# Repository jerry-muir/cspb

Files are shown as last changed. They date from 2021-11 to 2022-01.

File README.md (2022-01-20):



# Cluster System Power Board

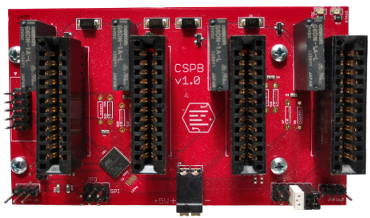
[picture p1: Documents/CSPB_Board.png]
CSPB


## About

The Cluster System Power Board (CSPB) is a power distribution and control platform to simplify the construction of Single Board Computer Clusters. The power board is designed to allow for simple single cluster systems or complex multi board systems to be powered through one power supply and controlled from a single control module. Control of the power board is achieved via an i2c serial bus interface which can be chained across multiple power boards.
<br />

## The project
The project has three main components. The hardware design which can be found in the [Hardware](/Hardware) directory, the firmware code which can be found in the [Firmware](/Firmware) directory and some user interface software which can be found in the [Software](/Software) directory.

A detailed users manual can be found in the [Documents](\Documents)
 directory.
## Python package links:

[PIP cspb Package](https://pypi.org/project/cspb/)
<br />
[PIP cspb-tools Package](https://pypi.org/project/cspb-tools/)

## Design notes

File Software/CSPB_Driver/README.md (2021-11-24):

# cspb

The cspb package contains a python driver class for communications with the Cluster System Power Board (cspb) hardware.

## Introduction

The cspb package contains a wrapper driver around the smbus package. It enables easy communication with the cluster system power board hardware via an i2c bus.

Currently supported methods are:

- set_power

- shutdown

- signal_shutdown

- read_register

- write_register

- set_register_number

- send_command

## Dependencies

This driver depends on the [smbus](https://pypi.org/project/smbus/) package.

## CSPB code examples

### Example 1: Display the current power state

```
from cspb.CSPB import CSPB

i2c_bus_number = 1
i2c_address = 21
cspb = CSPB(i2c_bus_number, i2c_address)
power_state = cspb.read_register(cspb.PWR_STTS_REGSTR_ADDR)
print(power_state)
```

### Example 2: Request shutdown of all power slots

```
from cspb.CSPB import CSPB

i2c_bus_number = 1
i2c_address = 21
cspb = CSPB(i2c_bus_number, i2c_address)
cspb.shutdown(0xff)
```

## Installation Instructions

cspb is a pure Python and requires no compilation. Install as follows:

```
pip install cspb
```

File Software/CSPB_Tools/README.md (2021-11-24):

# cspb-tools

The Cluster System Power Board (cspb) tools package contains example python software for communicating with the cluster system power board hardware.

## Introduction

The cspb-tools package contains python code examples that make use of the cspb driver package to provide communications to the cluster system power board hardware via an i2c serial bus. The software was developed with a focus on the Raspberry Pi single board computer.

This package contains the following programs:

- cspb_gui:

     A basic graphical user interface for communicating with and programming 
the cspb hardware.

## Dependencies

This package depends on the [cspb](https://pypi.org/project/cspb/) package.

## Code Examples

Running the GUI application:

```
run_cspb_gui
```

## Installation Instructions

The cspb_tools package is pure Python and requires no compilation. Install as follows:

```
pip install cspb_tools
```

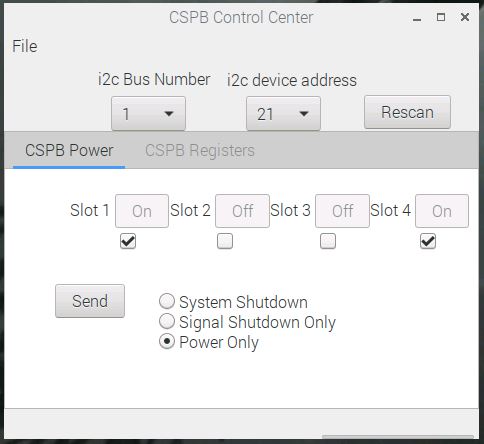
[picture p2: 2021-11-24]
Software/CSPB_Tools/app_pic.JPG

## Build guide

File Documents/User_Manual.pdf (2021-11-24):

# User Manual

## Cluster System Power Board

Version 1.1

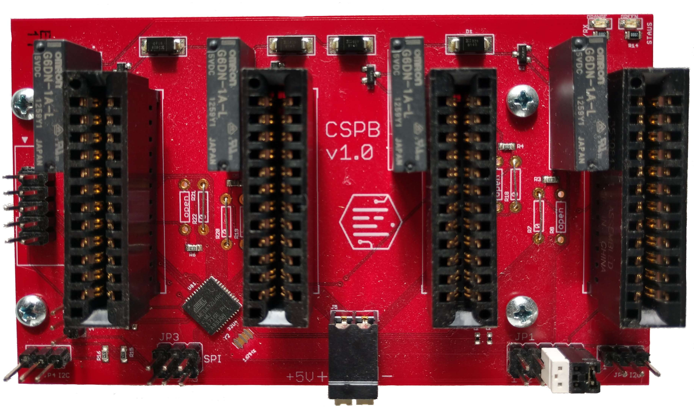
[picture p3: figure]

Version 1.1 | Page 1

Version 1.1 | Page 2

## Table of Contents

Version 1.1 | Page 3

Version 1.1 | Page 4

## Introduction

The Cluster System Power Board (CSPB) is a power distribution and control platform to simplify the construction of Single Board Computer Clusters. The power board is designed to allow for simple single cluster systems or complex multi board systems to be powered through one power supply and controlled from a single control module. Control of the power board is achieved via an i2c serial bus interface which can be chained across multiple power boards.

## Functional Description

The CSPB is a micro-controller based power board that allows easy control of power to individual single board computers. Each power board can hold up to four single board computers that conform to the Raspberry Pi 40 pin IO connector standard.
The CSPB is controlled via an i2c serial interface which can be connected to any i2c capable module via the i2c bus connector. Slot 1 of the CSPB is also available as an i2c bus connection via jumper terminals. This allows slot 1 to be the i2c control module for the CSPB.
Because the CSPB is controlled via an i2c interface, power boards can be chained together to form larger cluster systems that can be powered from one power supply and managed from one controller module. Each CSPB can be configured with a unique i2c address.
The CSPB can power on or off each slot individually, allowing single board computers to be added or removed with out impacting the cluster. The CSPB can also be configured to power up individual slots during it’s initial power up sequence. During the initial power up sequence a slot power up delay can be programmed to help manage current draw on the power supply.
The CSPB supports software shutdown of individual slots. The CSPB will signal the single board computer to perform a shutdown and wait for a control line to change state before removing power to the slot. This function has a programmable time out to ensure power down is completed.
The CSPB supports querying of the slot power states and shutdown states through register reads. Both programmable register functions and readable register functions are describe in more detail in the Registers section on page 17.
Jumper settings can be used to program default i2c addresses and i2c bus connections. Jumper settings are detailed in the Jumper Settings section on page 20.
The CSPB is power with 5.1V through a screwless spring loaded terminal block. The power circuit provides revers polarity protection.
The CSPB has two LED indicators, one for active power to the board and a second to indicate micro-controller activity during command processing.
Version 1.1 | Page 5

The CSPB can be mounted to a chassis or other mounting surface via the four 2.75mm mounting holes.

## Typical Configurations:

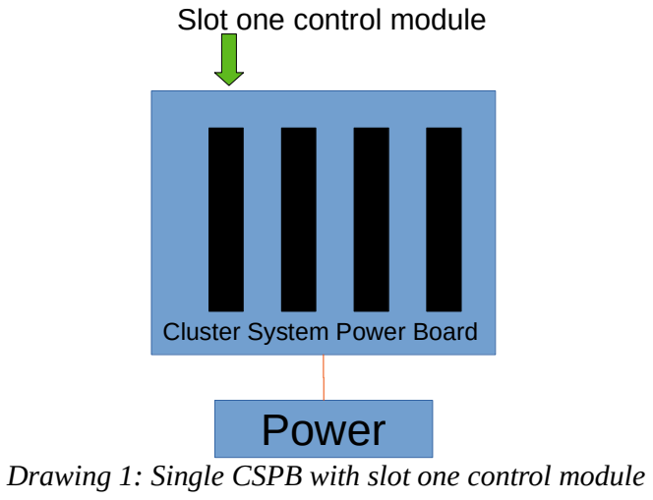
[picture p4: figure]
Power; Slot one control module; Cluster System Power Board
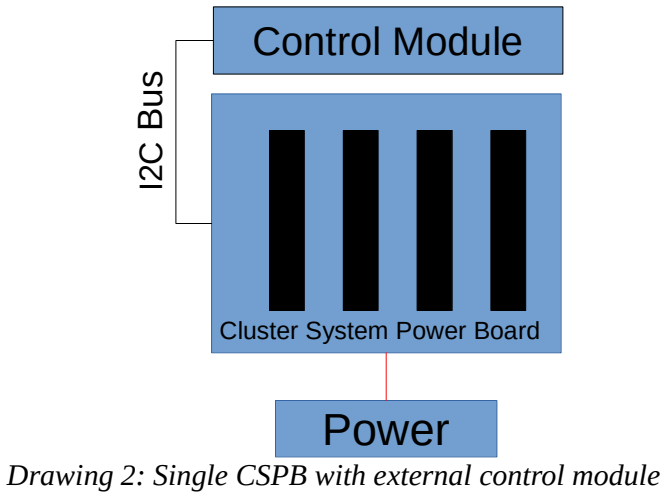
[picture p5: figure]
Power; Control Module; Cluster System Power Board

Version 1.1 | Page 6

Drawing 2: Single CSPB with external control module I2C Bus

Drawing 1: Single CSPB with slot one control module

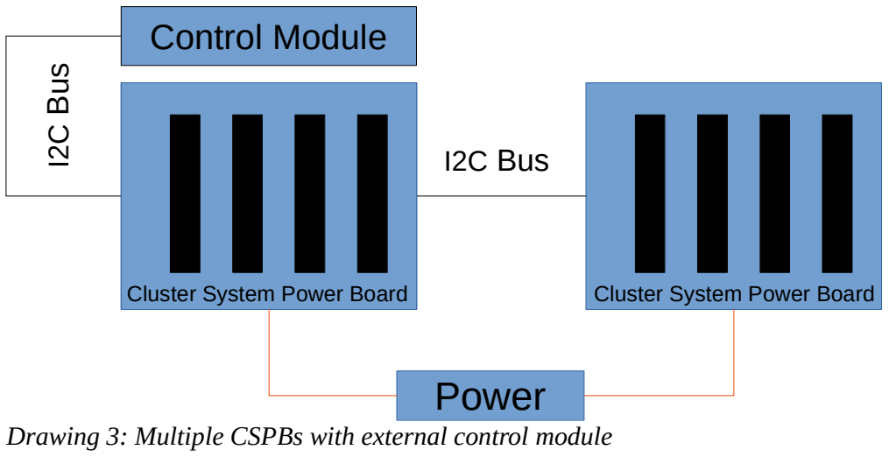
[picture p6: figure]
Control Module; Power; I2C Bus
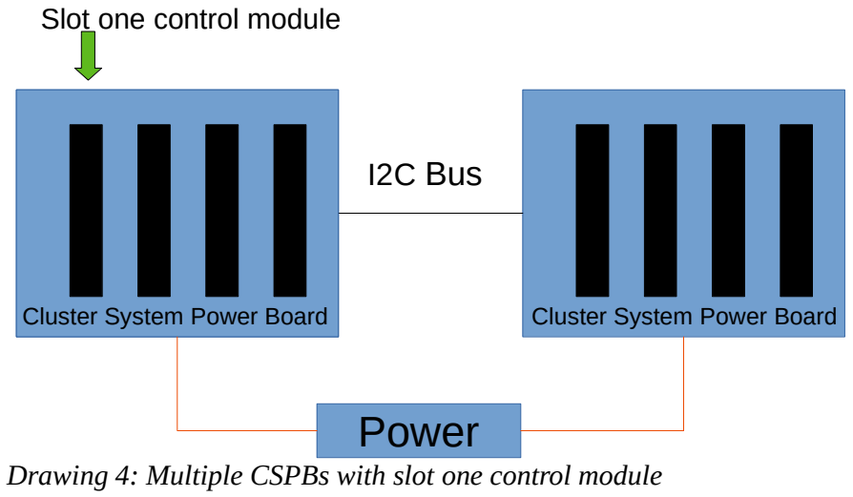
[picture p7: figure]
Cluster System Power Board; Power; I2C Bus; Slot one control module

Version 1.1 | Page 7

Drawing 3: Multiple CSPBs with external control module

Cluster System Power Board | Cluster System Power Board I2C Bus

Drawing 4: Multiple CSPBs with slot one control module

Cluster System Power Board | Cluster System Power Board

## Hardware Description

## Board Layout

The CSPB provides software controlled power distribution to the connected single board computers. There is a push terminal power connector for easy connection to a central power supply. LED indicators are provided for ‘power on’ and ‘board status’. Two i2c connectors are located at either end of the board and can be used to connect to a controller module and or to chain CSPB together is so desired. A jumper block is provided for configuring i2c bus connections and default address settings.

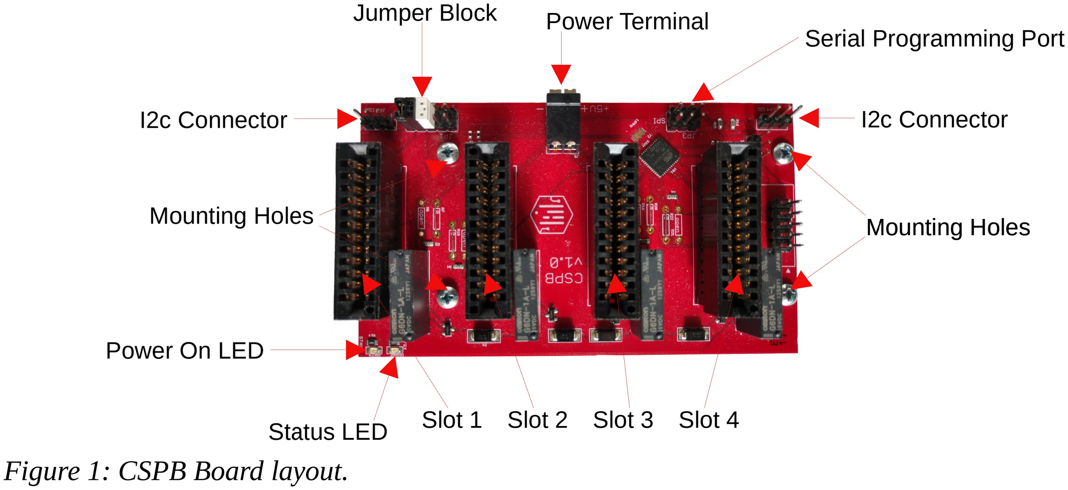
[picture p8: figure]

## Power Specification

The power specification below were developed with the Raspberry Pi single board computer in mind, however other single board computers using the Raspberry Pi 40 pin header specification should also work.

Parameter | Value | Min | Max
Input Voltage¹ | 5.1 V | 4.75 V | 5.25 V
Nominal Current | 218 mA²

1 The input voltage can vary according to the single board computer requirements. 2 This value does not include the current draw of the single board computers.

Version 1.1 | Page 8

## Dimensions

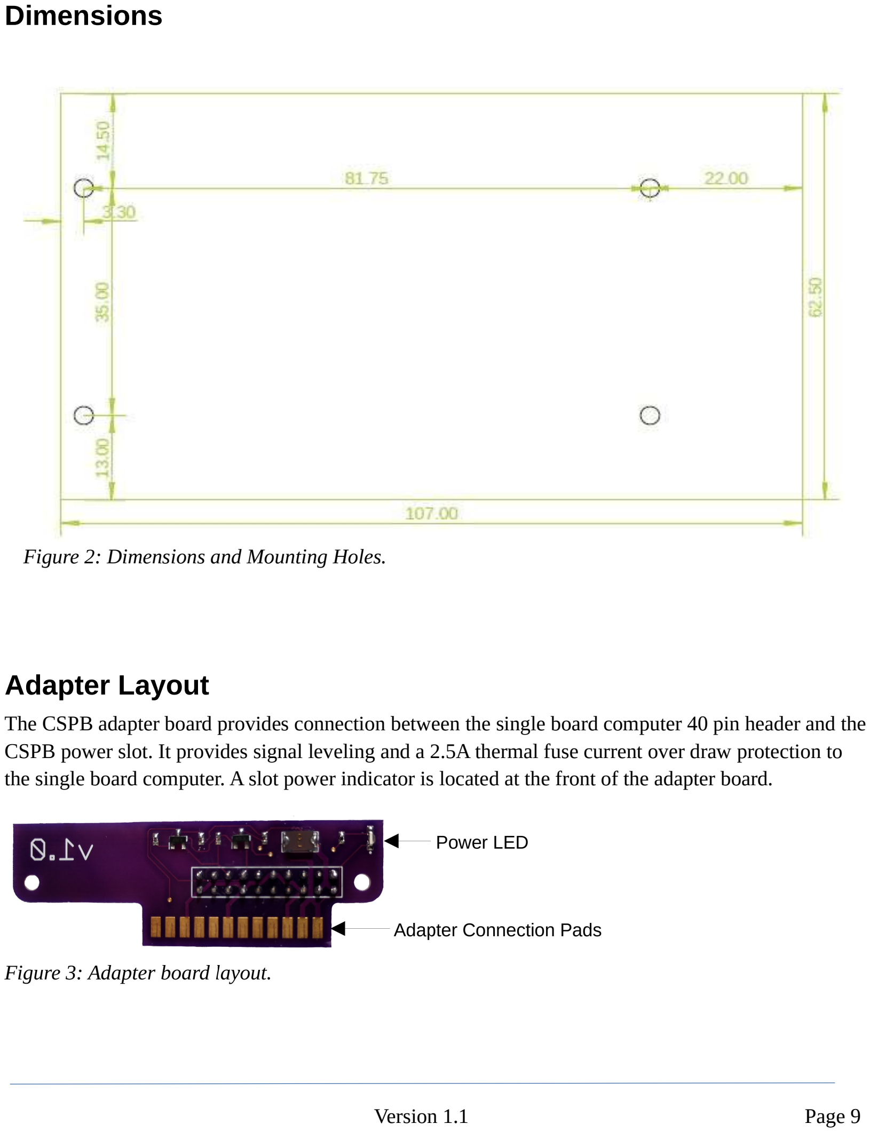
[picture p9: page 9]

## Adapter Layout

The CSPB adapter board provides connection between the single board computer 40 pin header and the CSPB power slot. It provides signal leveling and a 2.5A thermal fuse current over draw protection to the single board computer. A slot power indicator is located at the front of the adapter board.

Version 1.1 | Page 9

Figure 2: Dimensions and Mounting Holes.

## I2c Connector Layout

There are two i2c connector on either side of the CSPB labeled JP4 and JP5. As seen in Figure 4, the connector pins are numbered from left to right starting with pin 1. The connector layout is as follows:

Table 1: i2c Connector Signals
Pin Number Signal Name

### 1 SDA 2 GND 3 SCL

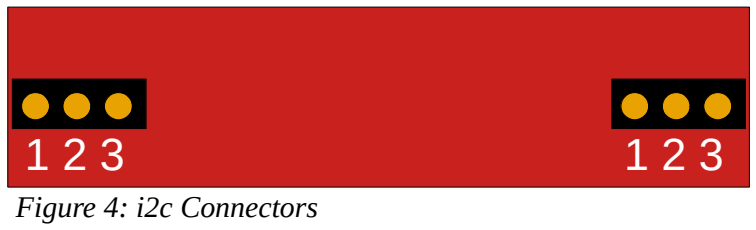
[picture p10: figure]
Figure 4: i2c Connectors

## Component Assembly

To assemble a cluster system using the CSPB, first the adapter board must be attached to the single board computer. In Figure 5, a Raspberry Pi single board computer is shown in its proper orientation with respect to the adapter board and the CSPB. The adapter is placed over to the first 20 pins of the 40 pin single board computer header such that the power indicator is facing the front of the single board computer and the adapter connection pads are facing away from the single board computer. In the case of the Raspberry Pi, this will place the power adapter LED on the same side as the single board computer LEDs. A nut and bolt can now be inserted through the single board computer and adapter board mounting holes.

Warring! It is necessary to connect the adapter board to the single board computer in the correct orientation. Failure to do so may result in damage to the single board computer and or the CSPB!

Version 1.1 | Page
10

!

The adapter board with the single board computer attached, See Figure 6, is then inserted into the CSPB power slot such that the adapter power LED is facing the same side as the status indicators on the CSPB.

Warring! It is necessary to insert the adapter board to the CSPB in the correct orientation. Failure to do so may result in damage to the single board computer and or the CSPB!

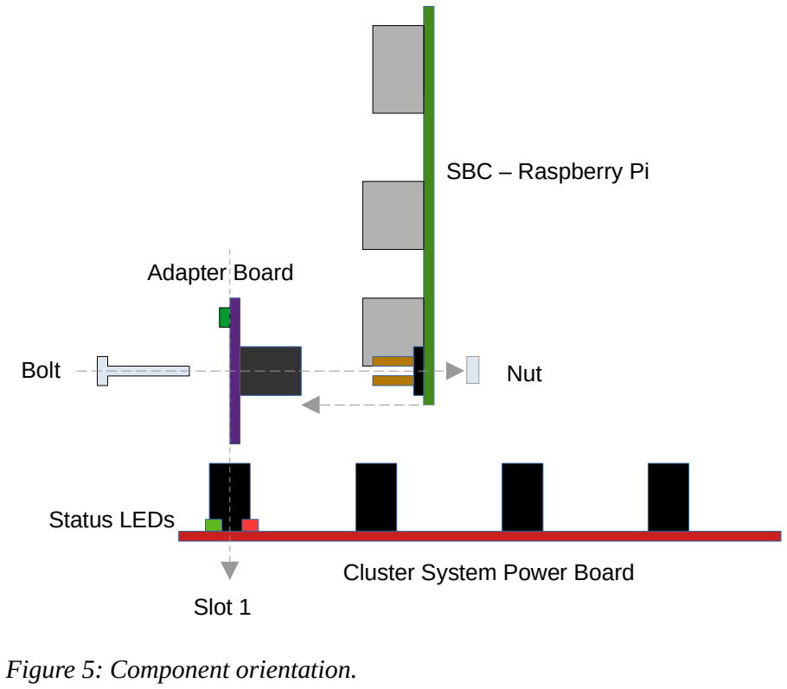
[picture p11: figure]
Figure 5: Component orientation.; SBC – Raspberry Pi; Bolt; Nut; Adapter Board; Cluster System Power Board; Status LEDs; Slot 1

Version 1.1 | Page
11

!

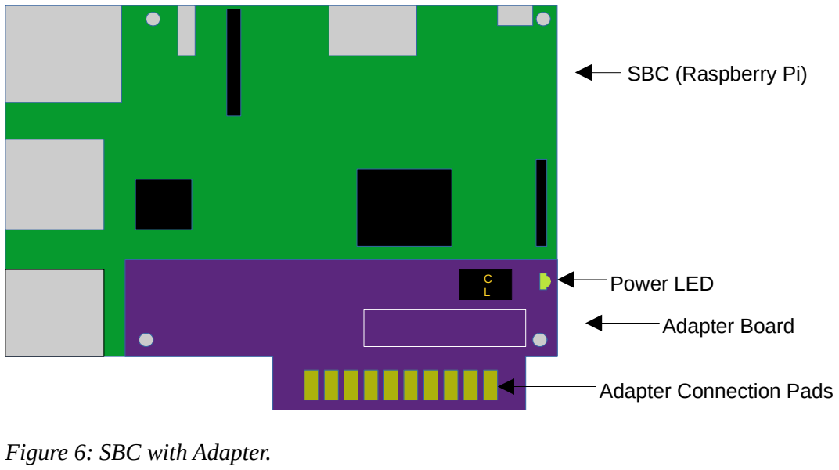
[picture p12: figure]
Figure 6: SBC with Adapter.; Adapter Board; Power LED; Adapter Connection Pads; SBC (Raspberry Pi)

Version 1.1 | Page
12

## Command Summary

ASCII commands to control the function of the CSPB are sent to via the i2c buss interface. These commands support the slot power functions and read/writes of the data registers. Reading register data is accomplished through an i2c data request.

Function | Command | Reply
Shutdown | # data
Signal Shutdown | $ data
Set Power State | ! data
Write Register | W register data
Set Read Register | R | data

## Command Quick Reference

Table 2: Command Quick Reference

Command ASCII | Command Hex | Bytes | Data | Function | Response Bytes | Response Data
# | 0x23 | 2 | Slot state | Shutdown slot | - | -

$ | 0x24 | 2 | Slot state | Signal Shutdown | - | -
! | 0x21 | 2 | Slot state | Set power state | - | -
W | 0x57 | 3 | Register Number Data | Write Register | - | -
R | 0x52 | 2 | Register Number | Set read register address | - -
Version 1.1 | Page
13

## Command Set

Shutdown

Command | Bytes | Data | Function
# | 2 | Slot State | Instructs the CSPB to shutdown the specified slots. A bit value of one indicates a shutdown will be performed.

Description: The shutdown command affects all slots. The slot state is written to the cluster system power board. Each bit of the slot state value affects the corresponding slot. The current slot state can be obtained by reading the slot power register.
Example:
| Shutdown slot 1: #1 (binary 0001)
| Shutdown slot 3: #4 (binary 0100)
| Shutdown slot 1 and 3: #5 (binary 0101)

Signal Shutdown

Command | Bytes | Data | Function
$ | 2 | Slot State | Instructs the CSPB to signal a shutdown to the specified slots. A bit value of one indicates that the signaling will be performed.

Description: The signal shutdown command affects all slots. The slot state is written to the cluster system power board. Each bit of the slot state value affects the corresponding slot. Example:
Signal Shutdown on slot 1: $1 (binary 0001)
Signal Shutdown on slot 3: $4 (binary 0100) Signal Shutdown on slot 1 and 3: $5 (binary 0101)
Version 1.1 | Page
14

Power

Command | Bytes | Data | Function
! | 2 | Slot State | Instructs the CSPB to set the slot power state for each slot

Description: The power command affects all slots. The slot state is written to the cluster system power board. Each bit of the slot state value affects the corresponding slot. To change the state of one slot with out affecting the other slots, the current slot state is required. The current slot state can be obtained by reading the slot power register.
Example:
Shutdown slot 1: #1 (binary 0001)
Shutdown slot 3: #4 (binary 0100) Shutdown slot 1 and 3: #5 (binary 0101)

Write Register

Command | Bytes | Data | Function
W | 3 | Register Number, Data Byte | Writes the data byte to the specified register address.

Description: The write register command will one byte the the specified register address. See the register address table for defined register addresses.
Example:
Write 15 to the i2c address register (0): W015
Version 1.1 | Page
15

Set Read Register

Command | Bytes | Data | Function
R | 2 | Register Number | Set the read register in the CSPB.

Description: The set read register command will set a pointer on the CSPB to the specified register number. A subsequent i2c read will return the byte data in that register.
Example:
Set the read register pointer in the CSPB to register 0, the i2c boot address: R0
A i2c byte data request will now return the data byte in register 0.
Version 1.1 | Page
16

## Registers

The CSPB has several programmable function registers and two readable state registers. These registers are accessed through the Read Register and Write Register commands describe in the Command Set section on page 14.
Table 3 provides a summery of the register addresses and functions.

Table 3: Register Addresses
Register
Address
| Bit | Default Value
Hexadecimal

Default Value
Decimal

Function

0 | 0-7 | 0x30 | 48 | i2c bus address
1 | 0 | 0x01 | 1 | Slot 1 boot on power up
| 1 | 0x01 | 1 | Slot 2 boot on power up
| 2 | 0x01 | 1 | Slot 3 boot on power up
| 3 | 0x01 | 1 | Slot 4 boot on power up
| 4 | 0x00 | 0 | Reserved for future use.
| 5 | 0x00 | 0 | Reserved for future use.
| 6 | 0x00 | 0 | Reserved for future use.
| 7 | 0x00 | 0 | Reserved for future use.
2 | 0 | 0x00 | 0 | Slot 1 i2c master indicator
| 1-7 | 0x00 | 0 | Reserved for future use.
3 | 0-7 | 0x64 | 100 | Power up delay in 20 milliseconds increments
4 | 0-7 | 0x32 | 50 | Power down signal duration in 20 millisecond increments
5 | 0-7 | 0x0A | 10 | Shutdown timeout in seconds
6-255 | 0-7 | 0xFF | 255 | Reserved for future use.
128 | 0-7 | 0x00 | 0 | Monitor line state values for each slot
129 | 0-7 | 0x00 | 0 | Power state values for each slot
Note: Registers 128 and 129 are read only.

## Register Details

### 0 - i2c Address

This register contains the i2c address of the CSPB upon power up. It is user programmable to any valid i2c address in the range of decimal 9-255. The default is decimal 48. Attempting to program addresses below decimal 9 are ignored.

Version 1.1 | Page
17

### 1 - Power up on boot

The first 4 bits of this programmable register indicate which slots will be powered on during the CSPB initial power up sequence. The least significant bit maps to slot 1. The default value is decimal 15 (binary 00001111). A 1 indicates that power will be applied. The last 4 bits are reserved for future use.

### 2 - Miscellaneous

This programmable register contains miscellaneous function values. The first bit can be set to 1 to indicate that slot one on the CSPB contains the i2c controller module. Bit one is optional and is defaulted to 0.
The next seven bits are reserved for future use.

### 3 - Slot power up delay

This programmable register contains the slot power up delay in 20 millisecond increments. During the initial CSPB power up sequence, each slot can be powered on. The power up delay can be used to introduce a delay between the application of power to each slot so as to reduce current loads on the power supply. The default is 100, which results in a two second delay between the application of power to each slot.

### 4 - Slot power down signal duration

This programmable register contains the duration of the power down signal in 20 millisecond increments. The power down signal is applied to a single board computer to trigger a software shutdown of the computer. The default value is 50 which results in a 1 second duration.

### 5 - Slot shutdown timeout

This programmable register contain the power down timeout value in seconds. When a shutdown command is issued, the CSPB will monitor the single board computer shutdown line for a state transition. If this transition is not seen within the timeout period, the CSPB will remove power from the slot after the timeout period has expired. This prevents an infinite power down time. The default is 10 seconds.

### 128 - Monitor line State

The first 4 bits of this read only register contain the monitor line state of each slot. The least significant bit maps to slot 1. This register can be used query the monitor line for a given slot to determine monitor line state transitions. A 1 indicates a high state and a 0 indicates a low state. The last 4 bits are not used.

Version 1.1 | Page
18

### 129 - Slot Power State

The first 4 bits of this read only register contain the power state of each slot. The least significant bit maps to slot 1. This register can be used query the power state for a given slot. A 1 indicates that power is on and 0 indicates that power is off. A binary value of 0001111 would indicate that power is applied to all 4 slots. The last 4 bits are not used.

Version 1.1 | Page
19

## Jumper Settings

Jumper Number | Function | Setting
1 | Default i2c Address | Use i2c address 0x30, decimal 48
2 | Alternate i2c Address | Use i2c address 0x15, decimal 21
3 | i2c SDA connector | Connect to Slot 1 SDA line
4 | i2c SCL connector | Connect to Slot 1 SCL line
5 | I2c 3.3v connector | Connect i2c 3.3V source

## Jumper Description

### Jumper 1

Short this jumper to ignore the programmed i2c address and use the decimal 48 address. This jumper takes precedence over jumper 2.

### Jumper 2

Short this jumper to ignore the programmed i2c address and use the decimal 21 address.

### Jumper 3

Short this jumper to connect the i2c SDA line on slot one to the i2c SCL bus line. To use slot one as the CSPB control module, jumpers 4 and 5 must also be shorted.

### Jumper 4

Short this header to connect the i2c SCL line on slot one to the i2c SCL bus line. To use slot one as the CSPB control module, jumpers 3 and 5 must also be shorted.

### Jumper 5

Short this jumper to connect the 3.3V line on slot one to the i2c 3.3V source line. To use slot one as the CSPB control module, jumpers 3 and 4 must also be shorted.

Version 1.1 | Page
20

## Configuring the single board computer (Raspberry Pi)

The following configuration example is based on a Raspberry Pi single board computer loaded with the Raspbian Buster OS. Other single board computers may require different configuration settings or methods to achieve the desired default port behavior. In this example, the default port behavior is as follows:
- BCM GPIO port 22 shall be set high (3.3V) upon boot up of the single board computer.
- BCM GPIO port 22 shall be set low (0V) upon shutdown completion of the single board computer.
- BCM GPIO port 27 shall be set as an input in the low state. A high (3.3V) signal by the CSPB shall indicate that the single board computer should shutdown.
This default port behavior can be configured by adding the following lines to the end of the /boot/config.txt file

## Python Software

There are two python PIP packages available as examples of interfacing with the CSPB hardware. The first is the cspb package that contains a basic hardware driver and the second is the cspb-tools package which contains a rudimentary graphical user interface. Both packages were developed with the Raspberry Pi Raspbian operating system as the intended operating environment.

## cspb Package

The cspb PIP package contains a basic hardware driver for the cluster system power board. It uses the smbus package for low level data communications across the i2c bus. It can be imported in to your python code to control the power board functions.

Version 1.1 | Page
21

# On boot up, set GPIO22 to be an output with a value of 1 which is 3.3V. (This is BCM pin Number) gpio=22=op,dh

# Set a shutdown signal on GPIO27 with a transition from low to high. dtoverlay=gpio-shutdown,gpio_pin=27,active_low=0,gpio_pull=up

# Drive the Monitor pin low at power off. dtoverlay=gpio-poweroff,gpiopin=22,active_low

### Installation

To install the package on a Raspbian OS:

### Example usage

Example 1: To shutdown all power slots

## csb-tools Package

The cspb-tools package contains a rudimentary graphical user interface that allows for control and programming of the cluster system power board. It uses the cspb python package for communications with the power board. This user interface was developed with the Raspberry Pi Raspbian operating system as its intended operating environment.

### Installation

To install the package on a Raspbian OS:

### Running the user interface

Version 1.1 | Page
22

pip install cspb

from cspb.CSPB import CSPB

i2c_bus_number = 1
i2c_device_address = 21
cspb = CSPB(i2c_bus_number, i2c_device_address) cspb.shutdown(#ff)

pip install cspb-tools

run_cspb_gui

### User Interface Description

The CSPB Power tab, see Figure 7, in the CSPB Control Center software can send one of 3 commands to the CSPB.
Each command as selected buy the radio button is analogous to the commands described in the Command Set section on page 14. Placing a check in the check box of a given slot will send a value 1 in the command for that slot. The current power state is displayed in the box to the right of the slot number.
The command will be sent to the board located on the selected i2c bus at the specified i2c address. The command will effect all slots. Therefore care should be taken to ensure that power is not inadvertently removed from slots that may need to remain on. This is especially true if the CSPB control module is configured in slot 1.
The CSPB Registers tab, see Figure 8, can be used to read and write values to the specific registers. Reading current register values is accomplished by simply selecting the Read button. Writing a value to a register is accomplished by placing a check in the Enable check box for the associated register and adding a value to be written in the accompanying value box. When the Write button is selected, all enabled fields are written.
Version 1.1 | Page
23

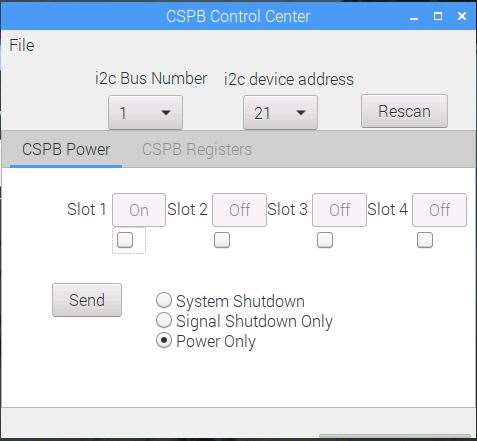
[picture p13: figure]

Version 1.1 | Page
24

Figure 7: CSPB Power Tab.

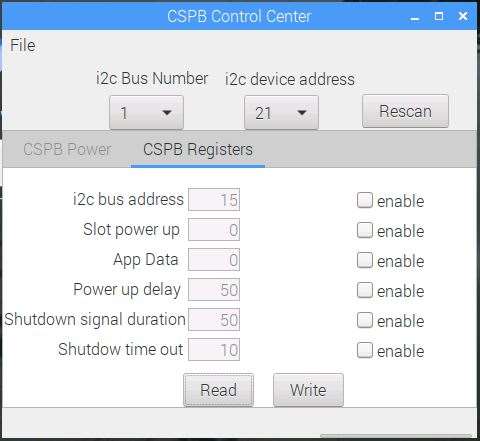
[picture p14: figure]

Version 1.1 | Page
25

Figure 8: CSPB Registers tab

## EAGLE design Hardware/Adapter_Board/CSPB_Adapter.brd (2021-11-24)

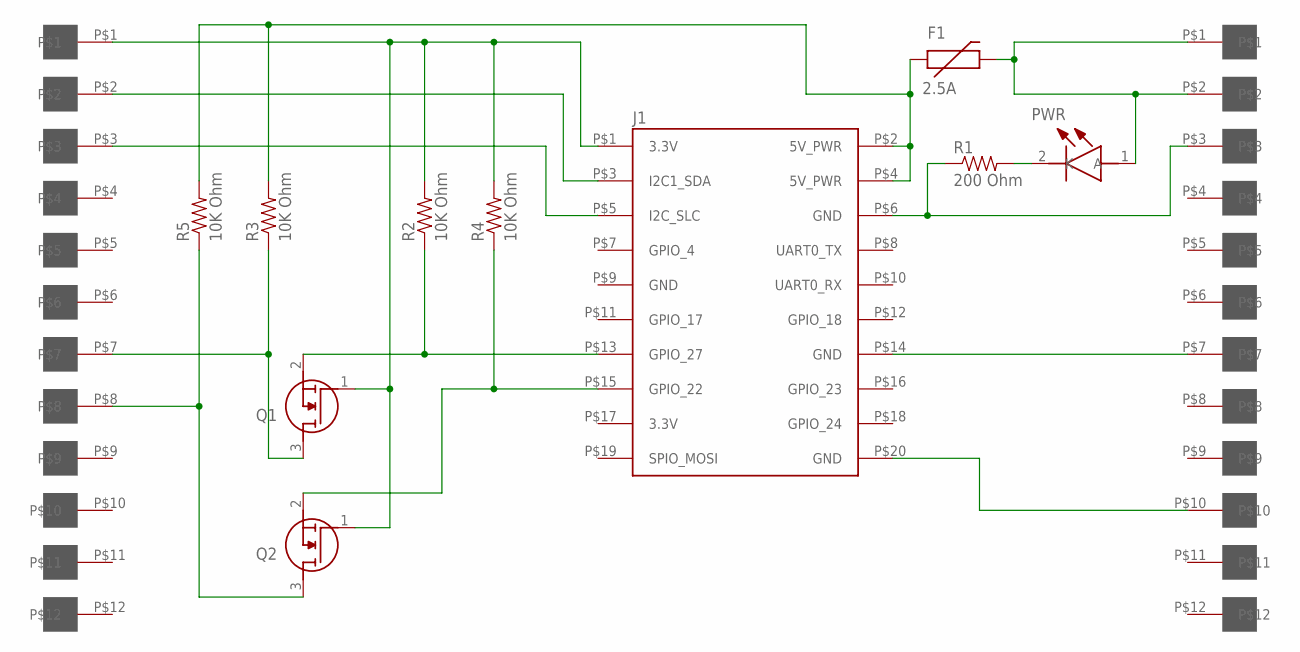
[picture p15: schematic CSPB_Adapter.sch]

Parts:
F1: 2.5A; F1812
J1: PPTC052LFBN-RC; 2X10_TH_HEADER_BOTTOM
J2, J3: 12_POS_BOARD_EDGE_PADS; CARD_EDGE_12_POS_0.1_IN
PWR: LTST-S220KGKT; LTSTS220KGKT
Q1, Q2: BSS138; SOT95P240X120-3N
R1: 200 Ohm; 0402-RES
R2, R3, R4, R5: 10K Ohm; 0402-RES

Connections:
3.3V: J1.P$1 (3.3V), J2.P$1, Q1.1 (G), Q2.1 (G), R2.2, R4.2
5V: F1.2, J3.P$1, J3.P$2, PWR.1 (A)
GND: J1.P$6 (GND), J1.P$9 (GND), J1.P$14 (GND), J1.P$20 (GND), J3.P$3, J3.P$7, J3.P$10, R1.1
MONITOR: J2.P$8, Q2.3 (D), R5.1
MONITOR_PI: J1.P$15 (GPIO_22), Q2.2 (S), R4.1
unnamed: F1.1, J1.P$2 (5V_PWR), J1.P$4 (5V_PWR), R3.2, R5.2
unnamed: PWR.2 (K), R1.2
SDA: J1.P$3 (I2C1_SDA), J2.P$2
SHUTDOWN: J2.P$7, Q1.3 (D), R3.1
SHUTDOWN_PI: J1.P$13 (GPIO_27), Q1.2 (S), R2.1
SLC: J1.P$5 (I2C_SLC), J2.P$3

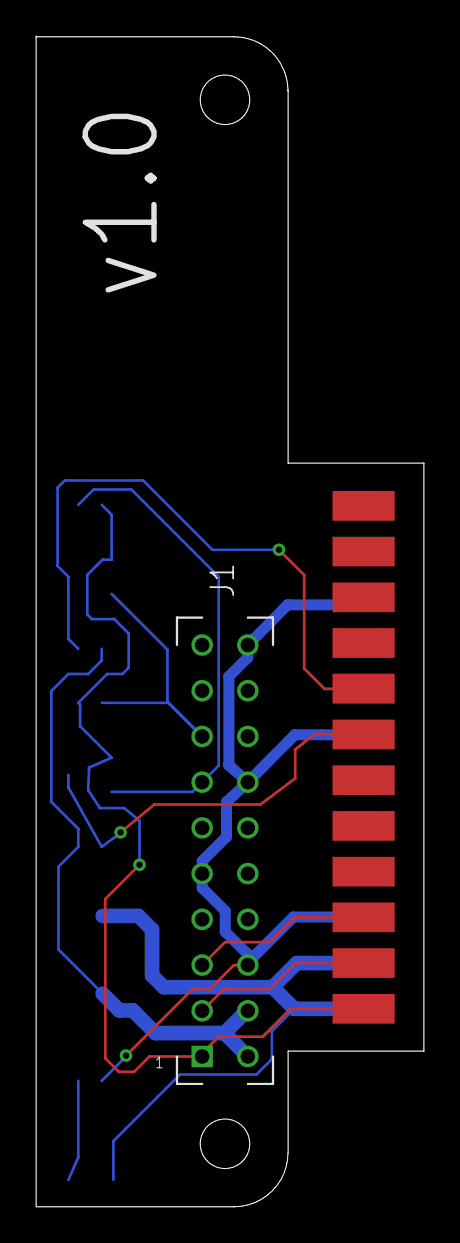
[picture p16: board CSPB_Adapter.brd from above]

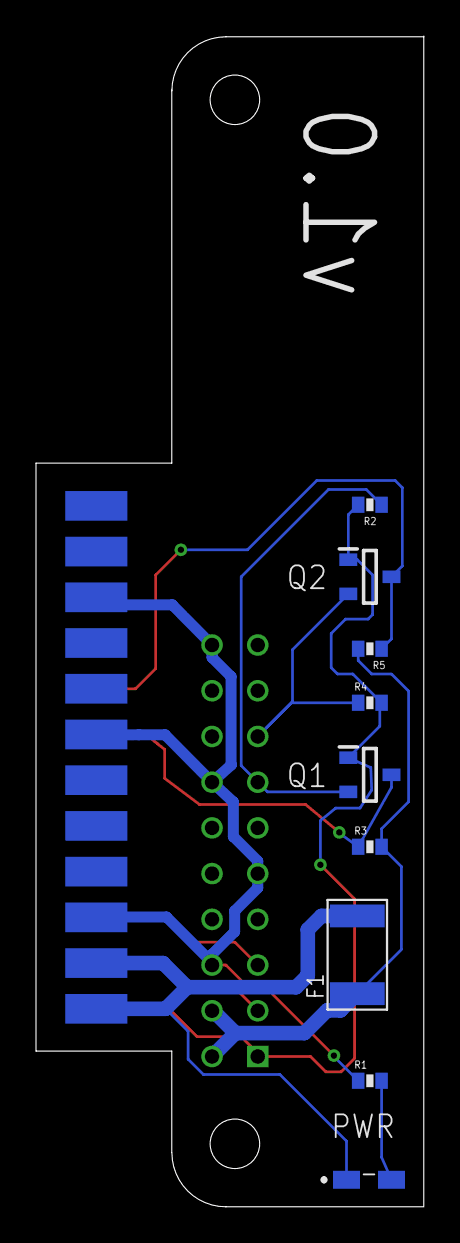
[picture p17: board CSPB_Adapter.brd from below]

Board: 2 copper layers, 21.6 x 65.0 mm, 12 parts (10 on the bottom side), 11 nets.

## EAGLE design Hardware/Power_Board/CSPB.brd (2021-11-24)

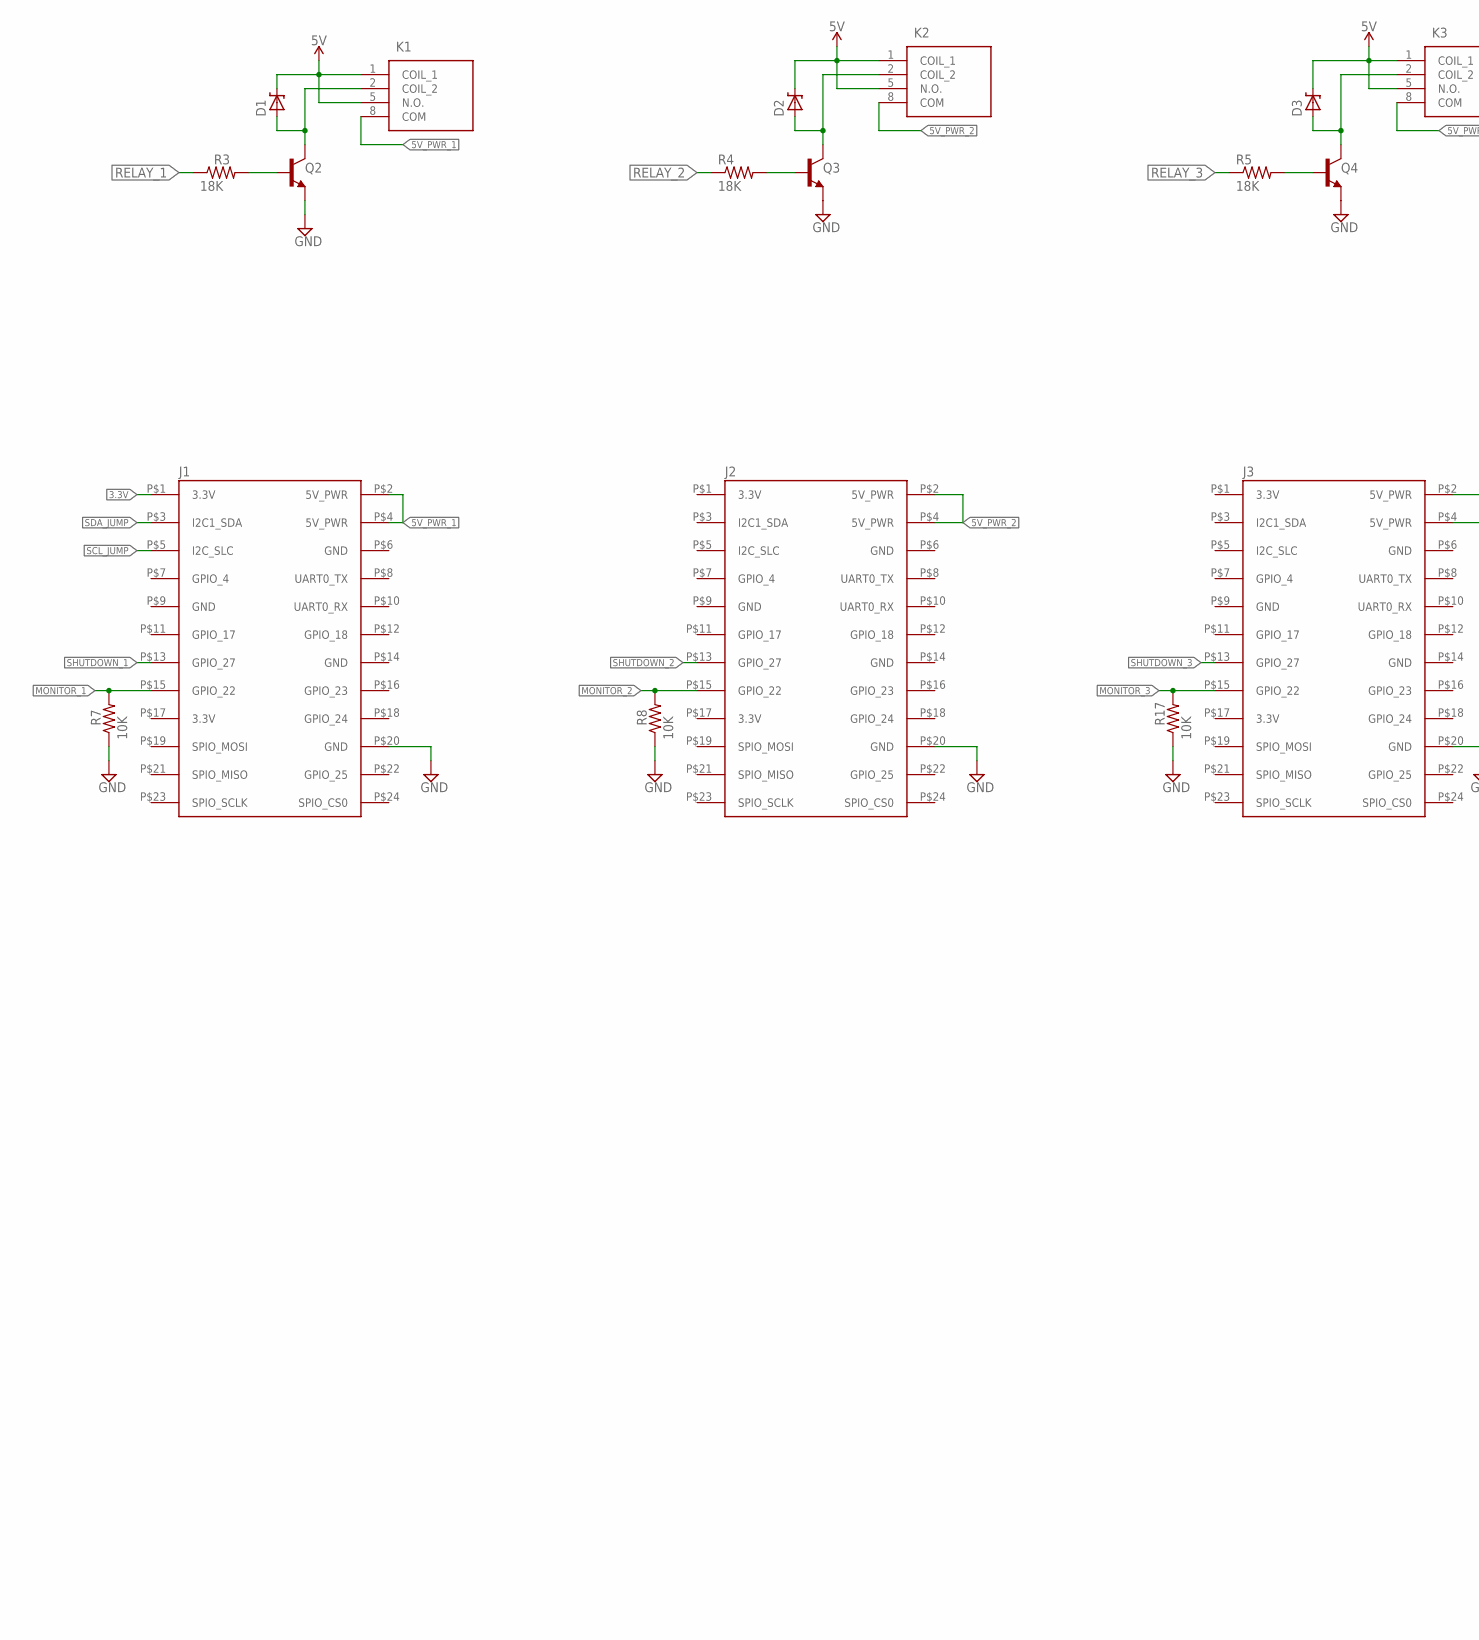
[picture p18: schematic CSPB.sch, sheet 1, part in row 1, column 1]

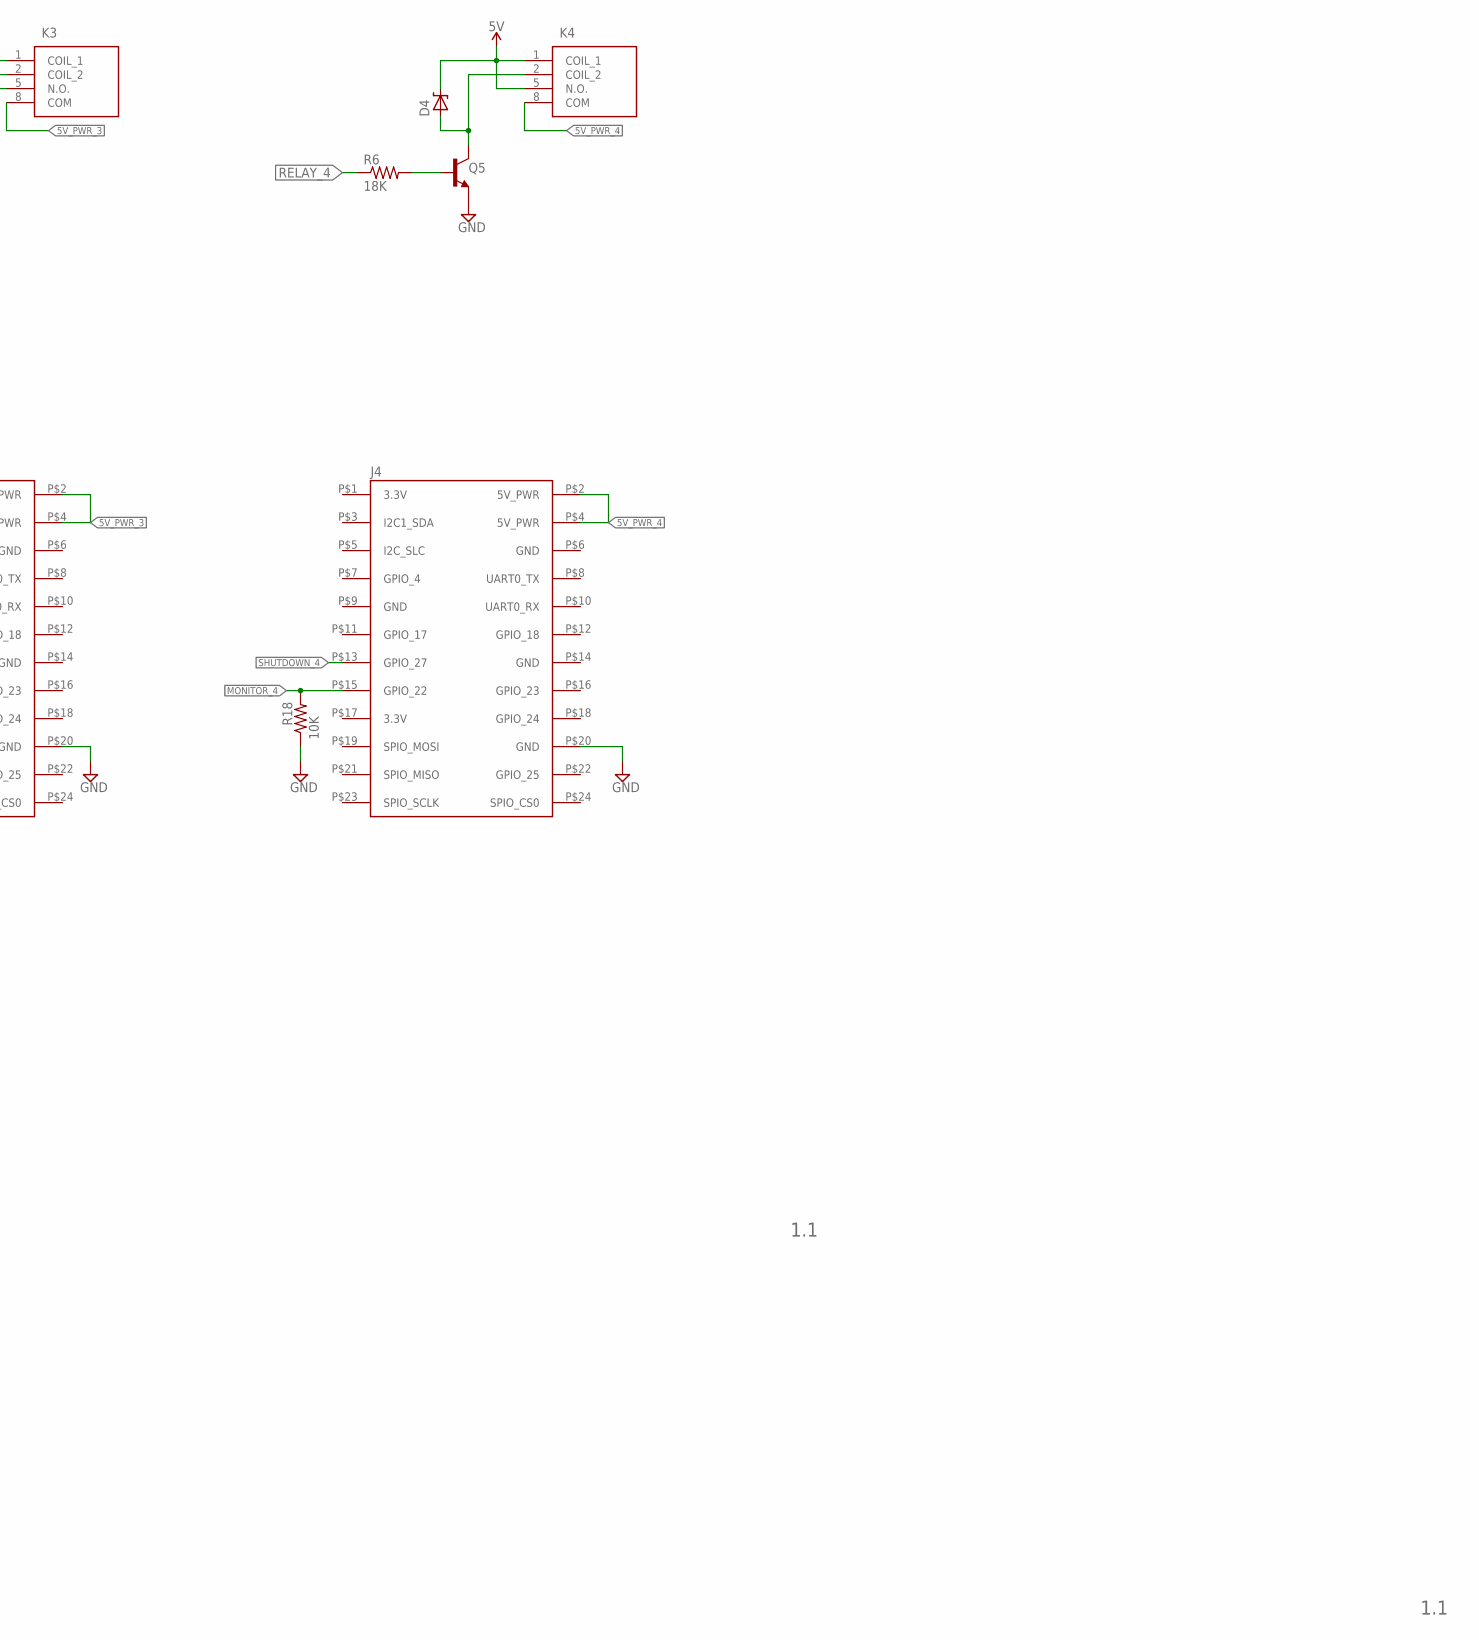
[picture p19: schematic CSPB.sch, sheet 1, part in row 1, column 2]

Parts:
D1, D2, D3, D4: 1A/23V/620mV; SMADIODE
J1, J2, J3, J4: 5530843-1; 2X12_TH_EDGE_CONN
K1, K2, K3, K4: G6DN-1A_DC5; G6DN-1A-L
Q2, Q3, Q4, Q5: 600mA/40V; SOT23-3
R3, R4, R5, R6: 18K; 0603-RES
R7, R8, R17, R18: 10K; 0603-RES

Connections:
3.3V: J1.P$1 (3.3V); also elsewhere on the board
5V: D1.C, D2.C, D3.C, D4.C, K1.1 (COIL_1), K1.5 (N.O.), K2.1 (COIL_1), K2.5 (N.O.), K3.1 (COIL_1), K3.5 (N.O.), K4.1 (COIL_1), K4.5 (N.O.); also elsewhere on the board
5V_PWR_1: J1.P$2 (5V_PWR), J1.P$4 (5V_PWR), K1.8 (COM)
5V_PWR_2: J2.P$2 (5V_PWR), J2.P$4 (5V_PWR), K2.8 (COM)
5V_PWR_3: J3.P$2 (5V_PWR), J3.P$4 (5V_PWR), K3.8 (COM)
5V_PWR_4: J4.P$2 (5V_PWR), J4.P$4 (5V_PWR), K4.8 (COM)
GND: J1.P$6 (GND), J1.P$9 (GND), J1.P$14 (GND), J1.P$20 (GND), J2.P$6 (GND), J2.P$9 (GND), J2.P$14 (GND), J2.P$20 (GND), J3.P$6 (GND), J3.P$9 (GND), J3.P$14 (GND), J3.P$20 (GND), J4.P$6 (GND), J4.P$9 (GND), J4.P$14 (GND), J4.P$20 (GND), Q2.2 (E), Q3.2 (E), Q4.2 (E), Q5.2 (E), R7.1, R8.1, R17.1, R18.1; also elsewhere on the board
MONITOR_1: J1.P$15 (GPIO_22), R7.2; also elsewhere on the board
MONITOR_2: J2.P$15 (GPIO_22), R8.2; also elsewhere on the board
MONITOR_3: J3.P$15 (GPIO_22), R17.2; also elsewhere on the board
MONITOR_4: J4.P$15 (GPIO_22), R18.2; also elsewhere on the board
unnamed: Q2.1 (B), R3.2
unnamed: D1.A, K1.2 (COIL_2), Q2.3 (C)
unnamed: Q4.1 (B), R5.2
unnamed: Q5.1 (B), R6.2
unnamed: D2.A, K2.2 (COIL_2), Q3.3 (C)
unnamed: D3.A, K3.2 (COIL_2), Q4.3 (C)
unnamed: D4.A, K4.2 (COIL_2), Q5.3 (C)
unnamed: Q3.1 (B), R4.2
RELAY_1: R3.1; also elsewhere on the board
RELAY_2: R4.1; also elsewhere on the board
RELAY_3: R5.1; also elsewhere on the board
RELAY_4: R6.1; also elsewhere on the board
SCL_JUMP: J1.P$5 (I2C_SLC); also elsewhere on the board
SDA_JUMP: J1.P$3 (I2C1_SDA); also elsewhere on the board
SHUTDOWN_1: J1.P$13 (GPIO_27); also elsewhere on the board
SHUTDOWN_2: J2.P$13 (GPIO_27); also elsewhere on the board
SHUTDOWN_3: J3.P$13 (GPIO_27); also elsewhere on the board
SHUTDOWN_4: J4.P$13 (GPIO_27); also elsewhere on the board

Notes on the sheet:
1.1

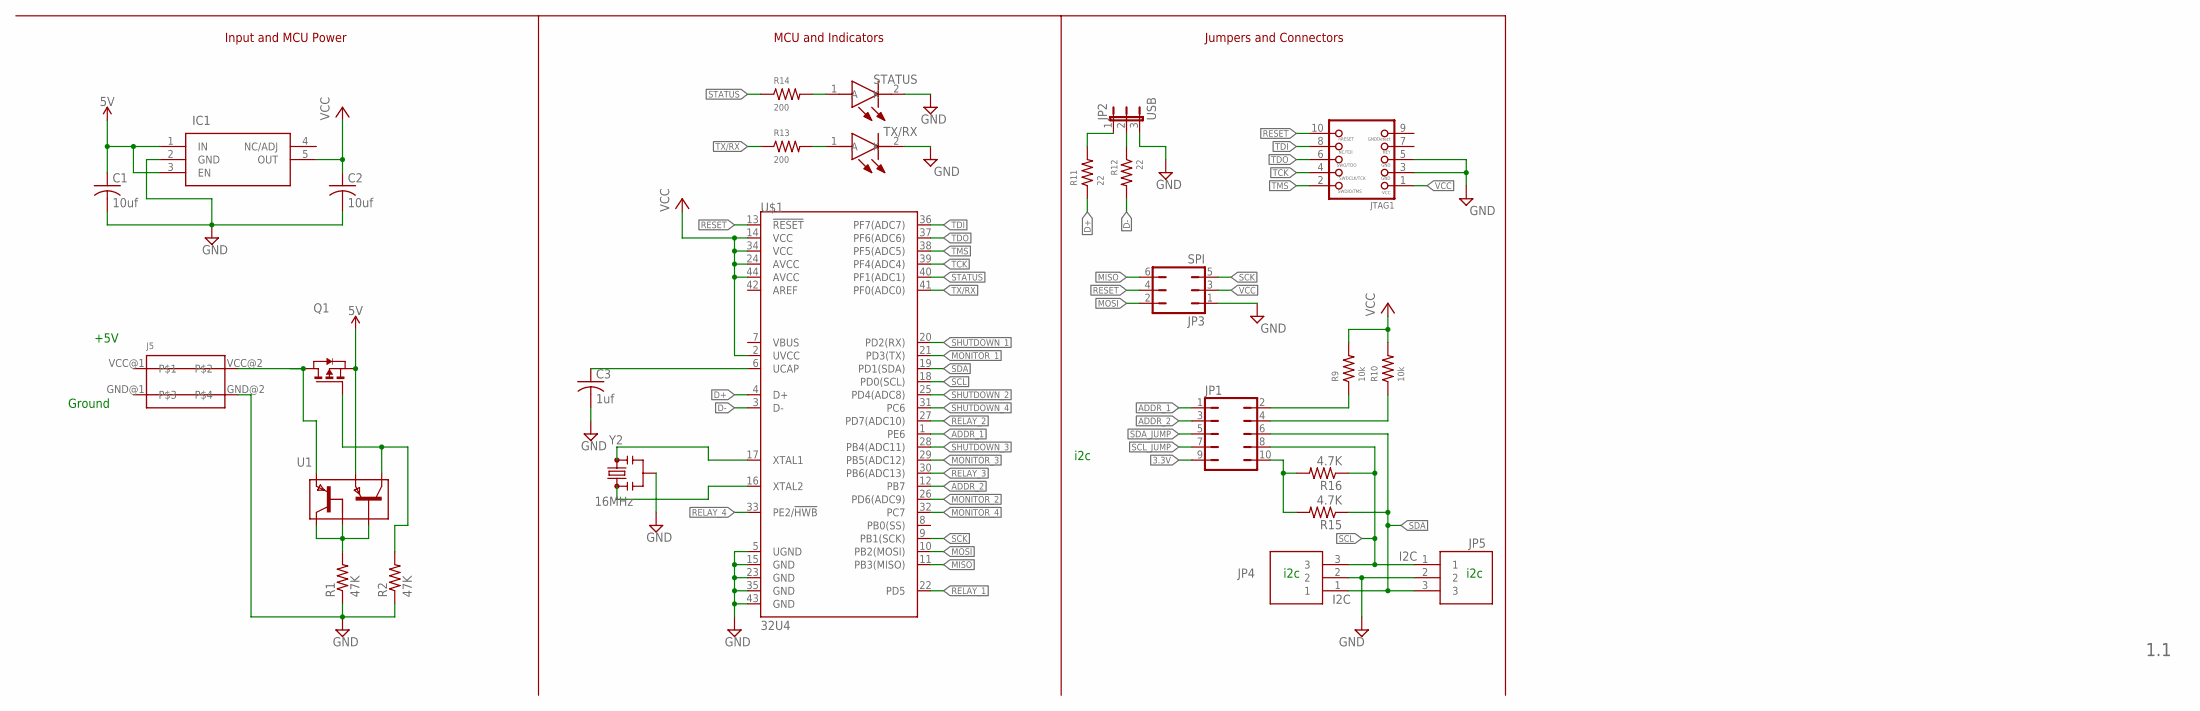
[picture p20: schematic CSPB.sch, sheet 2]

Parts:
C1, C2: 10uf; C1206
C3: 1uf; C1206
IC1: MIC5225-5.0YM5-TR; SOT95P280X130-5N
J5: 182442000; TB-2-POS-3_5MM-PITCH
JP1: JP5Q
JP2: USB; JUMPER3
JP3: SPI; JP3Q
JP4, JP5: I2C; SHDRRA3W50P0X200_1X3_790X760X4
JTAG1: JTAG-CORTEXM3MOLEX; CORTEXM3_SWD10_MOLEX
Q1: SQM40081EL; TO-263AB
R1, R2: 47K; 1206
R9, R10: 10k; 0402-RES
R11, R12: 22; 0402-RES
R13, R14: 200; 0805
R15, R16: 4.7K; 0603-RES
STATUS: LTST-S220KGKT; LTSTS220KGKT
TX/RX: LTST-S220KRKT; LTSTS220KGKT
U1: DMMT5401-7-F; SOT26-PNP
U$1: 32U4; QFN-44
Y2: 16MHz; RESONATOR-SMD-3.2X1.3

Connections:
3.3V: JP1.9; also elsewhere on the board
5V: C1.1, IC1.1 (IN), IC1.3 (EN), Q1.3 (S), U1.E2 (E1); also elsewhere on the board
ADDR_1: JP1.1, U$1.1 (PE6)
ADDR_2: JP1.3, U$1.12 (PB7)
D+: R11.1, U$1.4 (D+)
D-: R12.2, U$1.3 (D-)
GND: C1.2, C2.2, C3.2, IC1.2 (GND), J5.GND@2, JP2.3, JP3.1, JP4.2, JP5.2, JTAG1.3, JTAG1.5, R1.1, R2.1, STATUS.2 (K), TX/RX.2 (K), U$1.5 (UGND), U$1.15 (GND), U$1.23 (GND), U$1.35 (GND), U$1.43 (GND), Y2.2; also elsewhere on the board
MISO: JP3.6, U$1.11 (PB3(MISO))
MONITOR_1: U$1.21 (PD3(TX)); also elsewhere on the board
MONITOR_2: U$1.26 (PD6(ADC9)); also elsewhere on the board
MONITOR_3: U$1.29 (PB5(ADC12)); also elsewhere on the board
MONITOR_4: U$1.32 (PC7); also elsewhere on the board
MOSI: JP3.2, U$1.10 (PB2(MOSI))
unnamed: C3.1, U$1.6 (UCAP)
unnamed: R14.2, STATUS.1 (A)
unnamed: R13.2, TX/RX.1 (A)
unnamed: JP1.10, R15.2, R16.2
unnamed: R1.2, U1.B1 (B), U1.B2 (B1), U1.C1 (C)
unnamed: Q1.1 (G), R2.2, U1.C2 (C1)
unnamed: JP1.2, R9.1
unnamed: JP1.4, R10.1
unnamed: JP2.1, R11.2
unnamed: JP2.2, R12.1
P$1: J5.VCC@1
P$3: J5.GND@1
RELAY_1: U$1.22 (PD5); also elsewhere on the board
RELAY_2: U$1.27 (PD7(ADC10)); also elsewhere on the board
RELAY_3: U$1.30 (PB6(ADC13)); also elsewhere on the board
RELAY_4: U$1.33 (PE2/!HWB); also elsewhere on the board
RESET: JP3.4, JTAG1.10, U$1.13 (!RESET)
SCK: JP3.5, U$1.9 (PB1(SCK))
SCL: JP1.8, JP4.3, JP5.1, R16.1, U$1.18 (PD0(SCL))
SCL_JUMP: JP1.7; also elsewhere on the board
SDA: JP1.6, JP4.1, JP5.3, R15.1, U$1.19 (PD1(SDA))
SDA_JUMP: JP1.5; also elsewhere on the board
SHUTDOWN_1: U$1.20 (PD2(RX)); also elsewhere on the board
SHUTDOWN_2: U$1.25 (PD4(ADC8)); also elsewhere on the board
SHUTDOWN_3: U$1.28 (PB4(ADC11)); also elsewhere on the board
SHUTDOWN_4: U$1.31 (PC6); also elsewhere on the board
STATUS: R14.1, U$1.40 (PF1(ADC1))
TCK: JTAG1.4, U$1.39 (PF4(ADC4))
TDI: JTAG1.8, U$1.36 (PF7(ADC7))
TDO: JTAG1.6, U$1.37 (PF6(ADC6))
TMS: JTAG1.2, U$1.38 (PF5(ADC5))
TX/RX: R13.1, U$1.41 (PF0(ADC0))
VCC: C2.1, IC1.5 (OUT), JP3.3, JTAG1.1, R9.2, R10.2, U$1.2 (UVCC), U$1.14 (VCC), U$1.24 (AVCC), U$1.34 (VCC), U$1.44 (AVCC)
VCC_IN: J5.VCC@2, Q1.2 (D), U1.E1 (E)
XTAL1: U$1.17 (XTAL1), Y2.3
XTAL2: U$1.16 (XTAL2), Y2.1

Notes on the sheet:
i2c
+5V
Ground
Input and MCU Power
MCU and Indicators
Jumpers and Connectors
1.1

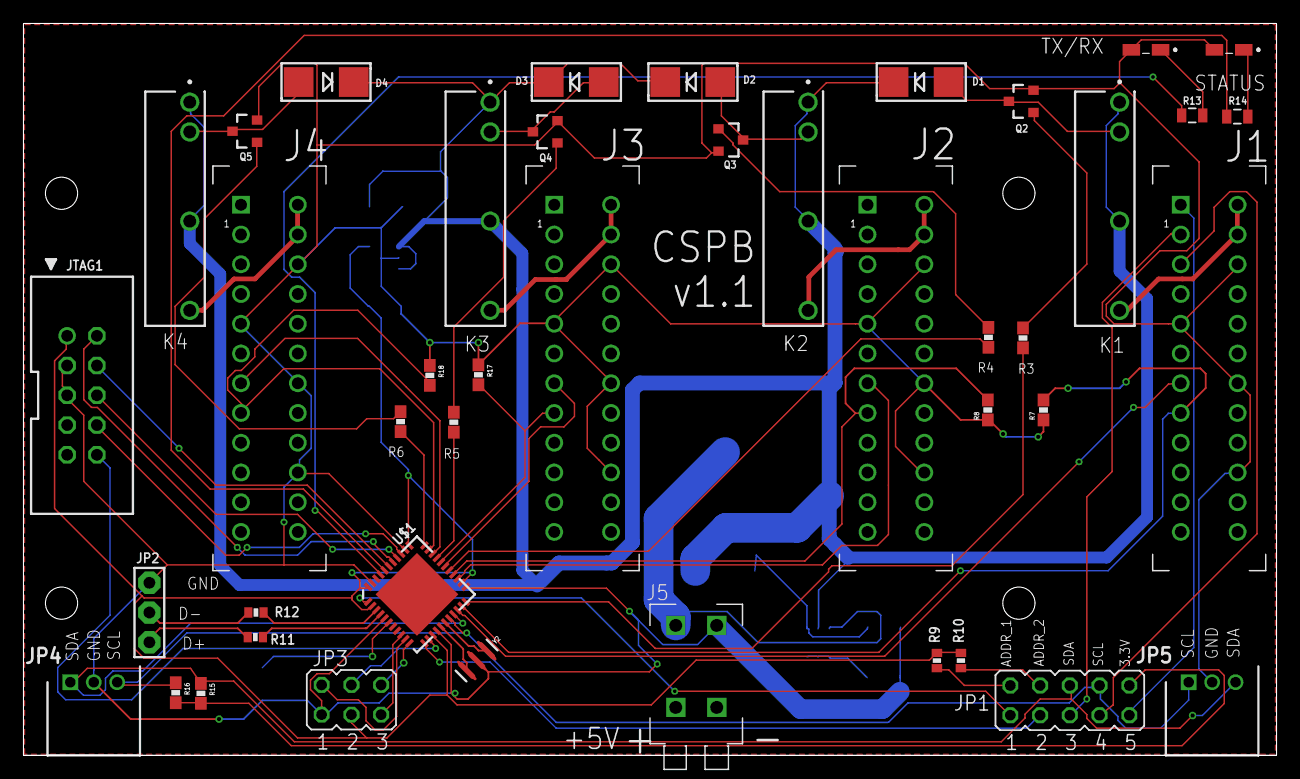
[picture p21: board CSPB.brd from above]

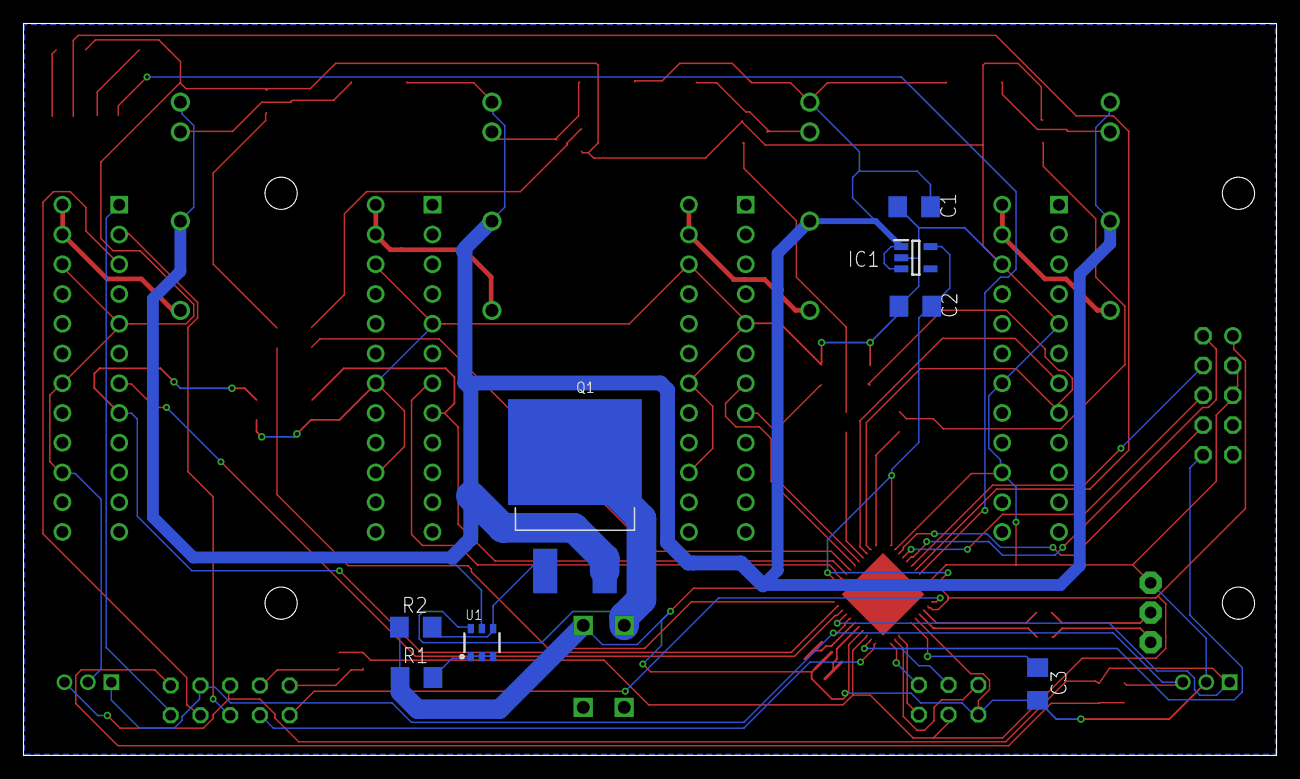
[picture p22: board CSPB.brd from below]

Board: 2 copper layers, 107.0 x 62.5 mm, 51 parts (8 on the bottom side), 59 nets.

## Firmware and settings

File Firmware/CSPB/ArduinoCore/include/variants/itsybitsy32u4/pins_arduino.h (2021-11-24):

/*
  pins_arduino.h - Pin definition functions for Arduino
  Part of Arduino - http://www.arduino.cc/

  Copyright (c) 2007 David A. Mellis

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
  $Id: wiring.h 249 2007-02-03 16:52:51Z mellis $
*/

#ifndef Pins_Arduino_h
#define Pins_Arduino_h

#include <avr/pgmspace.h>

// Workaround for wrong definitions in "iom32u4.h".
// This should be fixed in the AVR toolchain.
#undef UHCON
#undef UHINT
#undef UHIEN
#undef UHADDR
#undef UHFNUM
#undef UHFNUML
#undef UHFNUMH
#undef UHFLEN
#undef UPINRQX
#undef UPINTX
#undef UPNUM
#undef UPRST
#undef UPCONX
#undef UPCFG0X
#undef UPCFG1X
#undef UPSTAX
#undef UPCFG2X
#undef UPIENX
#undef UPDATX
#undef TCCR2A
#undef WGM20
#undef WGM21
#undef COM2B0
#undef COM2B1
#undef COM2A0
#undef COM2A1
#undef TCCR2B
#undef CS20
#undef CS21
#undef CS22
#undef WGM22
#undef FOC2B
#undef FOC2A
#undef TCNT2
#undef TCNT2_0
#undef TCNT2_1
#undef TCNT2_2
#undef TCNT2_3
#undef TCNT2_4
#undef TCNT2_5
#undef TCNT2_6
#undef TCNT2_7
#undef OCR2A
#undef OCR2_0
#undef OCR2_1
#undef OCR2_2
#undef OCR2_3
#undef OCR2_4
#undef OCR2_5
#undef OCR2_6
#undef OCR2_7
#undef OCR2B
#undef OCR2_0
#undef OCR2_1
#undef OCR2_2
#undef OCR2_3
#undef OCR2_4
#undef OCR2_5
#undef OCR2_6
#undef OCR2_7

#define NUM_DIGITAL_PINS   31
#define NUM_ANALOG_INPUTS  12

#define TXLED0			0
#define TXLED1			0
#define RXLED0			0
#define RXLED1			0
#define TX_RX_LED_INIT	        0

static const uint8_t SDA = 2;
static const uint8_t SCL = 3;
#define LED_BUILTIN 13

// Map SPI port to 'new' pins D14..D17
static const uint8_t SS   = 17;
static const uint8_t MOSI = 16;
static const uint8_t MISO = 14;
static const uint8_t SCK  = 15;

// Mapping of analog pins as digital I/O
// A6-A11 share with digital pins
static const uint8_t A0 = 18;
static const uint8_t A1 = 19;
static const uint8_t A2 = 20;
static const uint8_t A3 = 21;
static const uint8_t A4 = 22;
static const uint8_t A5 = 23;
static const uint8_t A6 = 24;	// D4
static const uint8_t A7 = 25;	// D6
static const uint8_t A8 = 26;	// D8
static const uint8_t A9 = 27;	// D9
static const uint8_t A10 = 28;	// D10
static const uint8_t A11 = 29;	// D12

#define digitalPinToPCICR(p)    ((((p) >= 8 && (p) <= 11) || ((p) >= 14 && (p) <= 17) || ((p) >= A8 && (p) <= A10)) ? (&PCICR) : ((uint8_t *)0))
#define digitalPinToPCICRbit(p) 0
#define digitalPinToPCMSK(p)    ((((p) >= 8 && (p) <= 11) || ((p) >= 14 && (p) <= 17) || ((p) >= A8 && (p) <= A10)) ? (&PCMSK0) : ((uint8_t *)0))
#define digitalPinToPCMSKbit(p) ( ((p) >= 8 && (p) <= 11) ? (p) - 4 : ((p) == 14 ? 3 : ((p) == 15 ? 1 : ((p) == 16 ? 2 : ((p) == 17 ? 0 : (p - A8 + 4))))))

//	__AVR_ATmega32U4__ has an unusual mapping of pins to channels
extern const uint8_t PROGMEM analog_pin_to_channel_PGM[];
#define analogPinToChannel(P)  ( pgm_read_byte( analog_pin_to_channel_PGM + (P) ) )

#define digitalPinHasPWM(p) ((p) == 3 || (p) == 5 || (p) == 6 || (p) == 9 || (p) == 10 || (p) == 11 || (p) == 13)

#define digitalPinToInterrupt(p) ((p) == 0 ? 2 : ((p) == 1 ? 3 : ((p) == 2 ? 1 : ((p) == 3 ? 0 : ((p) == 7 ? 4 : NOT_AN_INTERRUPT)))))

#ifdef ARDUINO_MAIN

// On the Arduino board, digital pins are also used
// for the analog output (software PWM).  Analog input
// pins are a separate set.

// ATMEL ATMEGA32U4 / ARDUINO LEONARDO / Flora
//
// D0				PD2					RXD1/INT2
// D1				PD3					TXD1/INT3
// D2				PD1		SDA			SDA/INT1
// D3#				PD0		PWM8/SCL	OC0B/SCL/INT0
// D4		A6		PD4					ADC8
// D5#				PC6		???			OC3A/#OC4A
// D6#		A7		PD7		FastPWM		#OC4D/ADC10
// D7				PE6					INT6/AIN0
//
// D8		A8		PB4					ADC11/PCINT4
// D9#		A9		PB5		PWM16		OC1A/#OC4B/ADC12/PCINT5
// D10#		A10		PB6		PWM16		OC1B/0c4B/ADC13/PCINT6
// D11#				PB7		PWM8/16		0C0A/OC1C/#RTS/PCINT7
// D12		A11		PD6					T1/#OC4D/ADC9
// D13#				PC7		PWM10		CLK0/OC4A
//
// A0		D18		PF7					ADC7
// A1		D19		PF6					ADC6
// A2		D20 	PF5					ADC5
// A3		D21 	PF4					ADC4
// A4		D22		PF1					ADC1
// A5		D23 	PF0					ADC0
//
// New pins D14..D17 to map SPI port to digital pins
//
// MISO		D14		PB3					MISO,PCINT3
// SCK		D15		PB1					SCK,PCINT1
// MOSI		D16		PB2					MOSI,PCINT2
// SS		D17		PB0					RXLED,SS/PCINT0
//
// TXLED	D30		PD5
// RXLED		        PB0
// HWB				PE2					HWB

// these arrays map port names (e.g. port B) to the
// appropriate addresses for various functions (e.g. reading
// and writing)
const uint16_t PROGMEM port_to_mode_PGM[] = {
	NOT_A_PORT,
	NOT_A_PORT,
	(uint16_t) &DDRB,
	(uint16_t) &DDRC,
	(uint16_t) &DDRD,
	(uint16_t) &DDRE,
	(uint16_t) &DDRF,
};

const uint16_t PROGMEM port_to_output_PGM[] = {
	NOT_A_PORT,
	NOT_A_PORT,
	(uint16_t) &PORTB,
	(uint16_t) &PORTC,
	(uint16_t) &PORTD,
	(uint16_t) &PORTE,
	(uint16_t) &PORTF,
};

const uint16_t PROGMEM port_to_input_PGM[] = {
	NOT_A_PORT,
	NOT_A_PORT,
	(uint16_t) &PINB,
	(uint16_t) &PINC,
	(uint16_t) &PIND,
	(uint16_t) &PINE,
	(uint16_t) &PINF,
};
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

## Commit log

2021-02-18 - Added adapter board hardware design files.
    [CSPB_Adapter.brd, CSPB_Adapter.sch]
2021-02-18 - Added Cluster System Power Board hardware design files.
    [CSPB.brd, CSPB.sch]
2021-02-19 - Update board picture to a more reasonable size.
2021-02-21 - updateing user manual to v.1.1 to match current hardware files.

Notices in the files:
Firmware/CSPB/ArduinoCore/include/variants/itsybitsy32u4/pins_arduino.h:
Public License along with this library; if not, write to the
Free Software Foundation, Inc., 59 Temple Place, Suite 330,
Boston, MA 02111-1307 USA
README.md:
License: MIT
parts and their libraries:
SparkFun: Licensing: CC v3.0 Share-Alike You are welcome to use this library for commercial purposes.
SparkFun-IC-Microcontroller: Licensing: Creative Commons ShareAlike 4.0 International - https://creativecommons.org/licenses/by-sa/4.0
